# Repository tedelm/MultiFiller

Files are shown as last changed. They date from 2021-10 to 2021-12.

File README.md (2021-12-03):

# MultiFiller
Modular Beercan/Bottle filler </br></br>
MultiFiller is a OpenSource semi-auto beercan or bottle filler.</br></br>

!This is a "work in progress" project!

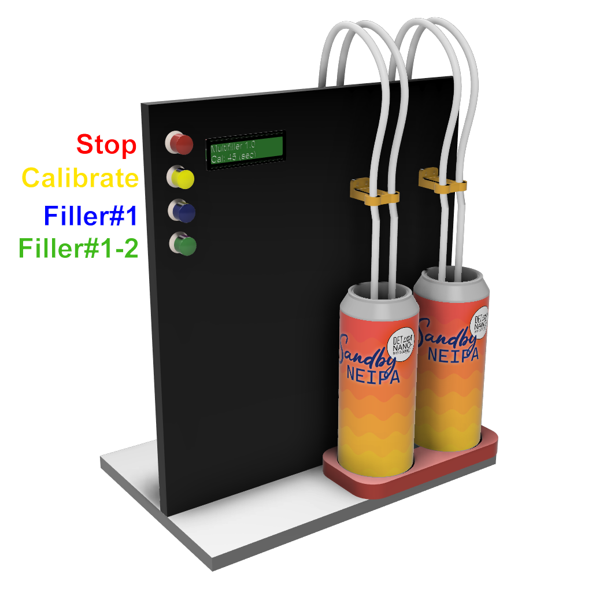
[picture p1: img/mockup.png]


## In action Youtube video
(https://youtu.be/LUoDoRMrJUI)

## Navigation 

* [Build](https://github.com/tedelm/MultiFiller/blob/main/Build/README.md)
* [Schematics](https://github.com/tedelm/MultiFiller/blob/main/Schematics/README.md)
* [Video(s)](https://youtu.be/LUoDoRMrJUI)
* [Parts](https://github.com/tedelm/MultiFiller/blob/main/Parts/readme.md)

## Todo/Checklist

Counter pressure filling

- [ ] Verify design
- [ ] Verify minimal foam build up when filling

## Counter Pressure filling

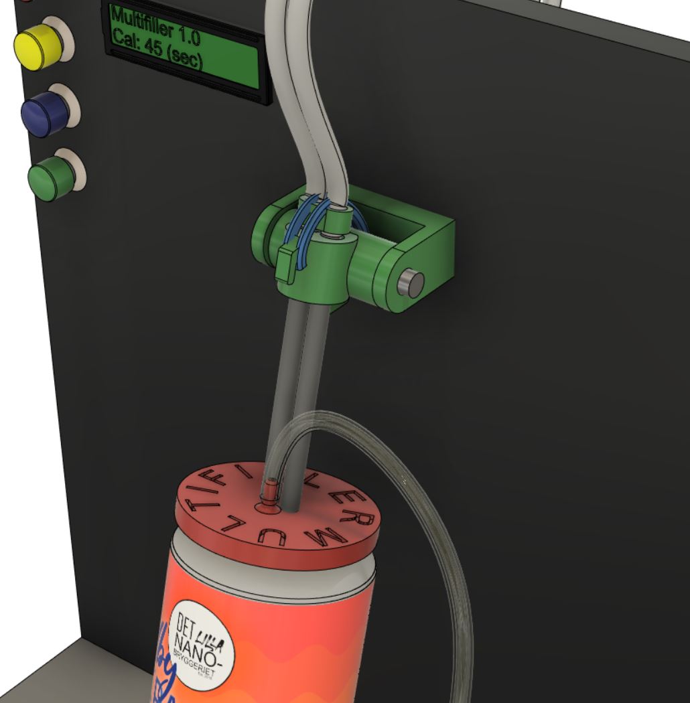
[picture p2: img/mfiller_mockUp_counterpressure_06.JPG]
</br>
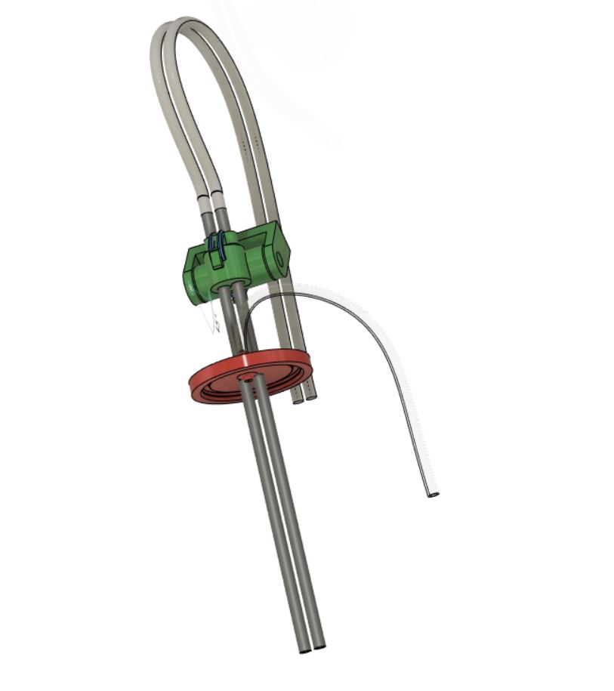
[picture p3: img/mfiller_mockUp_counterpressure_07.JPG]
</br>
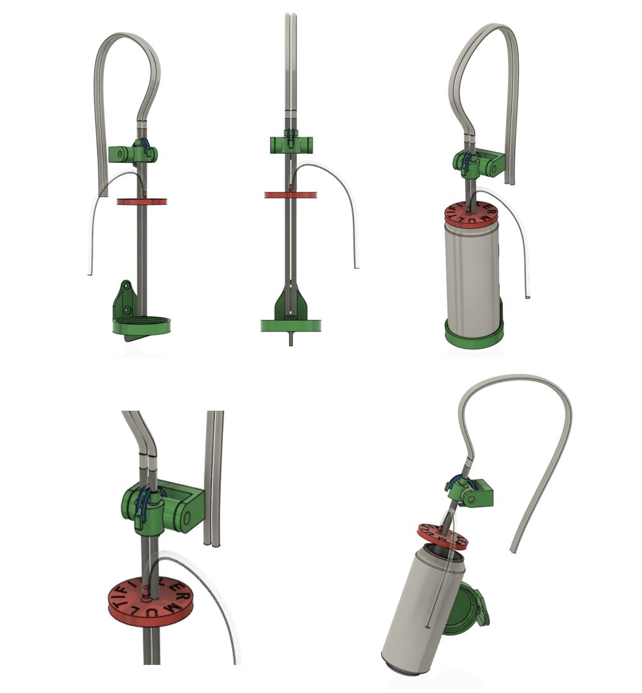
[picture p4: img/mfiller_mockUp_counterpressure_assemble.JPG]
</br>

Parts list:
- MFIller_CAN_CounterPressure_w_gasline_noVitamins-TPU.stl [STL List](https://github.com/tedelm/MultiFiller/tree/main/stl) or [Download - (RightClickSaveAs)](https://github.com/tedelm/MultiFiller/blob/main/stl/MFIller_CAN_CounterPressure_w_gasline_noVitamins-TPU.stl)
- MFiller_guide_cylinder_mount-PLA.stl  [STL List](https://github.com/tedelm/MultiFiller/tree/main/stl) or [Download - (RightClickSaveAs)](https://github.com/tedelm/MultiFiller/blob/main/stl/MFiller_guide_cylinder_mount-PLA.stl)
- MFiller_guide_cylinder-PLA_v1.1.stl  [STL List](https://github.com/tedelm/MultiFiller/tree/main/stl) or [Download - (RightClickSaveAs)](https://github.com/tedelm/MultiFiller/blob/main/stl/MFiller_guide_cylinder-PLA_v1.1.stl)
- MFiller_guide_cylinder-stopper-PLA_v1.1.stl   [STL List](https://github.com/tedelm/MultiFiller/tree/main/stl) or [Download - (RightClickSaveAs)](https://github.com/tedelm/MultiFiller/blob/main/stl/MFiller_guide_cylinder-stopper-PLA_v1.1.stl)
- MFiller_CAN_Shelf-PLA.stl    [STL List](https://github.com/tedelm/MultiFiller/tree/main/stl) or [Download - (RightClickSaveAs)](https://github.com/tedelm/MultiFiller/blob/main/stl/MFiller_CAN_Shelf-PLA.stl)
- 1/4" pipe/rod (stainless steel) [Link](https://www.maskindelen.se/product/rostfritt-ror-6x1)
- 1/4" tube (PVC/silicon) [Link](https://akvarieimporten.se/tillbehor/luftslang/pvc-luftslang-46-mm-transparent)
- 1/4" tube (PE) [Link](https://shop.humle.se/utrustning/slang/polyeten-pe/pe-slang-neutral-14-yd-per-meter)
- Rubberband (available at any random convenience store) [Link](https://www.clasohlson.com/se/Gummiband/p/Pr342290016)
- Optional:
    - Manual Air Valve 1/4" [Link](https://akvarieimporten.se/tillbehor/kopplingar-syresten/luftkran-i-plast-1-vags-for-luftslang-46-mm) (Could be used for Co2 inlet, Co2 Outlet, and beer lines)

</br>

# How to use
button#1 (Yellow) = Calibration (Press and hold)</br>
button#2 (Green)  = Filler #1 (Momentarily press)</br>
button#3 (Blue)   = Filler #1 and Filler #2 at same time (Momentarily press)</br>
button#4 (Red)    = Emergency shutdown (Press and hold)</br>

## Calibration
Button#1

    - Press and hold button#1 (it will start to pour beer from Filler #1)
    This is to calibrate how long it takes to fill your can or bottle
    When the can/bottle is filled to desired levels, release the button#1

</br>

## Test fill / Filler #1 
Button#2

    - Momentarily press button#2
       Filler#1: Co2 will purge for 4 seconds
       Filler#1: Beer flows for x (calibrated seconds)
       Filler#1: Co2 will purge on/off rapidly 8 times

## Filler #1 and #2
Button#3

    - Momentarily press button#3
       Filler#1 and #2: Co2 will purge for 4 seconds
       Filler#1 and #2: Beer flows for x (calibrated seconds)
       Filler#1 and #2: Co2 will purge on/off rapidly 8 times

</br>

## Emergency shutdown
button#4

    - Emergency shutdown (Press and hold)

</br>

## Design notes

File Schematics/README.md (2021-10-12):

# Schematics

</br>

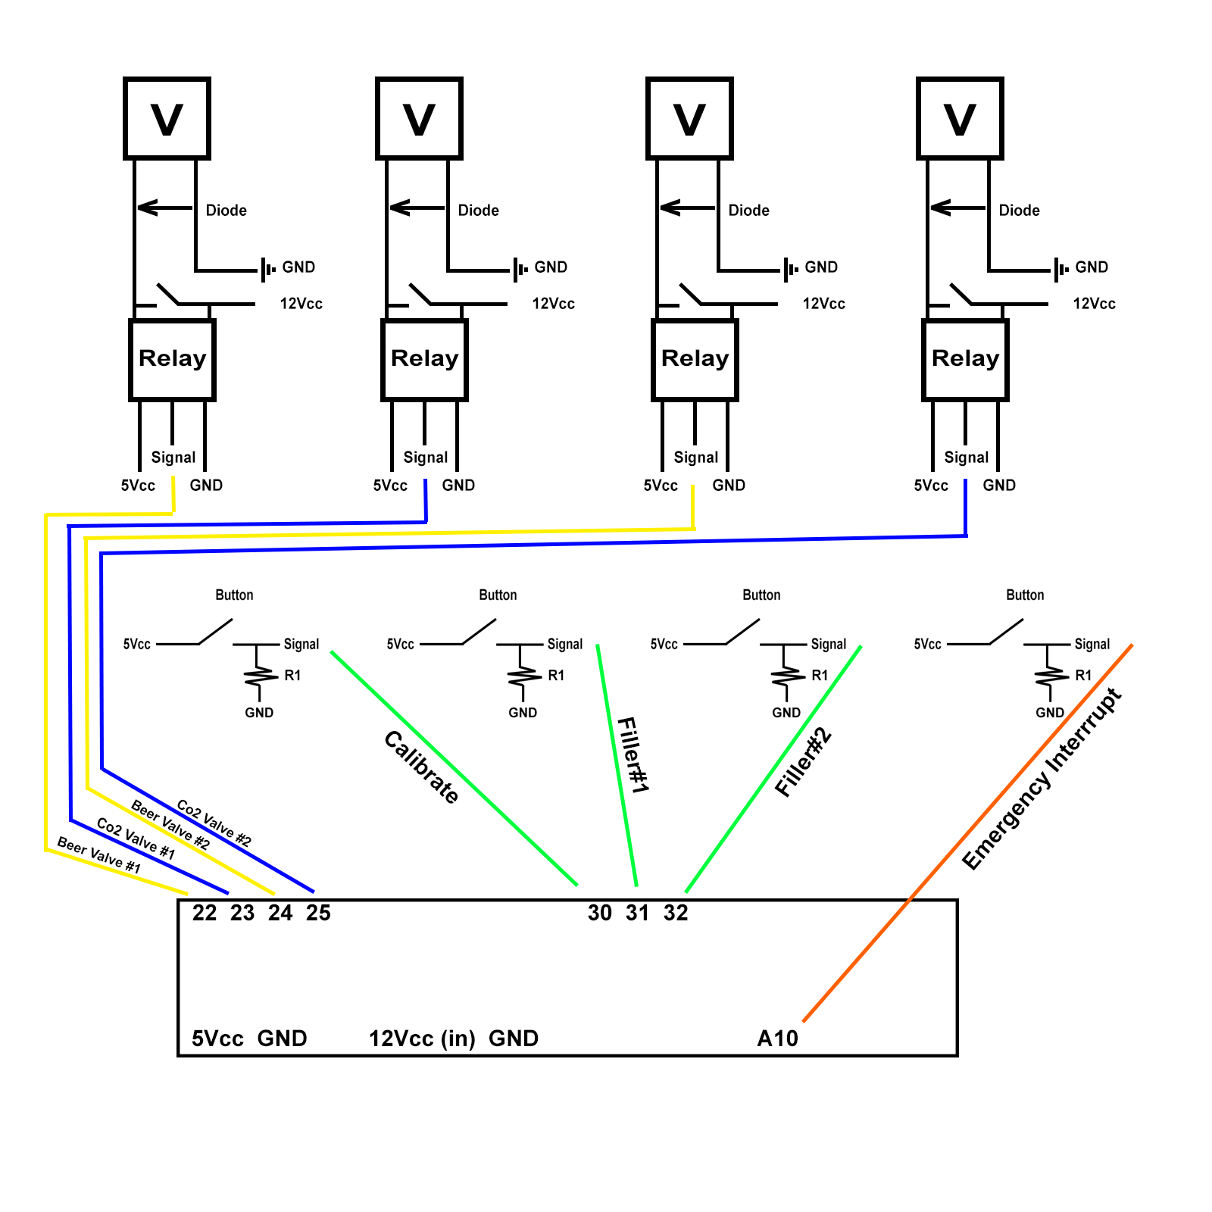
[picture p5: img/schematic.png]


</br>

## Buttons 
R1 = Resistor 10-50kOhm </br>
S = Signal, to arduino (eg. 30,31,32,A10)</br>

    //Calibrate - Time how long it takes to fill the can
    #define CalibrateButton 30 //Atmega328p-pu pin xx
    //Controller
    #define BeerFiller1Button 31 //Atmega328p-pu pin xx - Only Filler #1
    #define BeerFiller12Button 32 //Atmega328p-pu pin xx - Run both fillers
    #define EmergencyShutDownButton A10 //Atmega328p-pu interrupt pin xx - Stop everything
    //Arduino Uno/Nano/Mini: All pins are usable
    //Arduino Mega: 10, 11, 12, 13, 50, 51, 52, 53, A8 (62), A9 (63), A10 (64),A11 (65), A12 (66), A13 (67), A14 (68), A15 (69)

 </br>

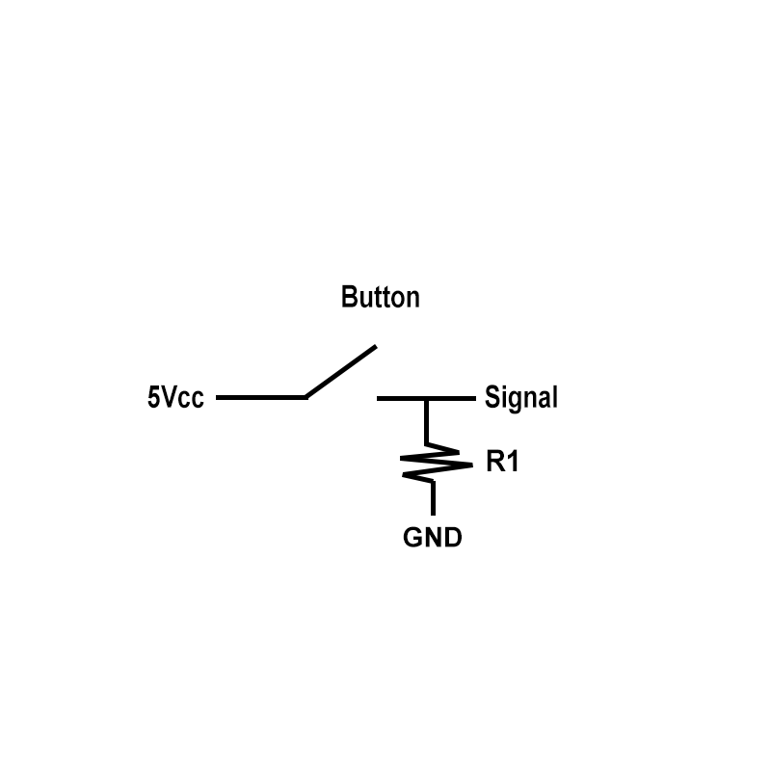
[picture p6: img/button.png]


## Relay and valves 
V = Solenoid valve</br>
<- = Diode </br>
S = Signal, to arduino (22,23,24,25)</br>

    //Filler 1
    #define BeerValve1 22 //Atmega328p-pu pin xx
    #define GasValve1 23 //Atmega328p-pu pin xx
    //Filler 2
    #define BeerValve2 24 //Atmega328p-pu pin xx
    #define GasValve2 25 //Atmega328p-pu pin xx

</br>

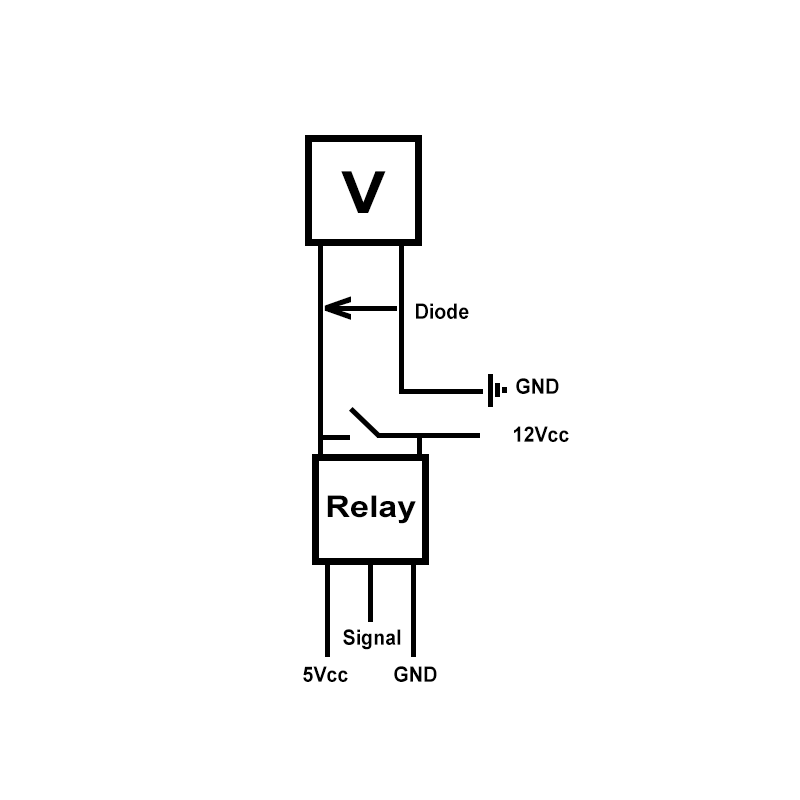
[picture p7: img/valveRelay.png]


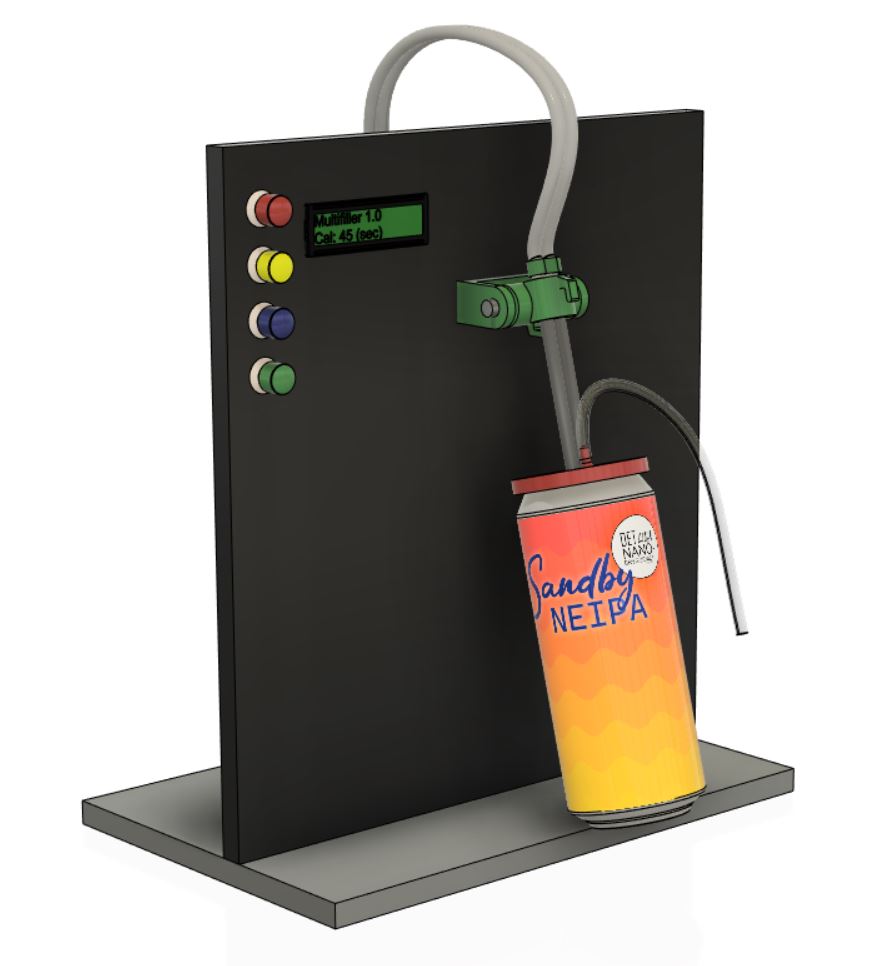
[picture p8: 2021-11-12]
img/mfiller_mockUp_counterpressure_04.JPG

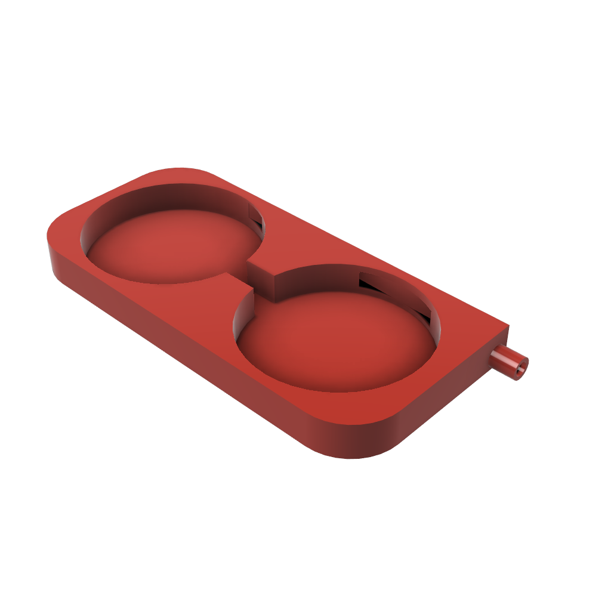
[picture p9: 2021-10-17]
img/can-tray.png

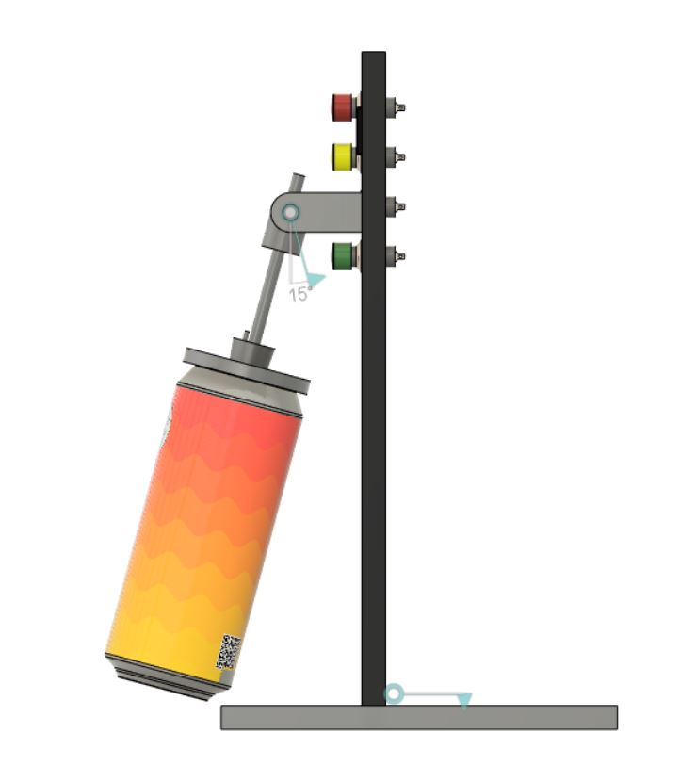
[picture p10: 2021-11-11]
img/mfiller_mockUp_counterpressure.JPG

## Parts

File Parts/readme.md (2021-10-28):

# Parts

## Single filler

|Pcs | Name | Price | Price subtotal (sek) | Description	| link |
| -- | --- | --- | --- | --- | ---- |
|2|12v solenoid valve - 1/4" (6,35mm) |	65  |130 |1 gas, 1 beer  |	https://www.wish.com/product/5de4e26dd52cb3c890403e0f|
|4|Diode (1N4001 DO-41 50V 1A) |	1.50  | 6 |Protect relay from solenoid kickback  |	https://www.electrokit.com/produkt/1n4001-do-41-50v-1a/|
|4|Resistor 0.25W 10-50kohm (10k) |	1  | 4 |Pulldown resistor  |	https://www.electrokit.com/produkt/motstand-kolfilm-0-25w-10kohm-10k/|
|2|PE-slang 1/4" (4,3 x 6,35 mm) neutral|	19	|38		|slang	 |https://shop.humle.se/utrustning/slang/polyeten-pe/pe-slang-neutral-14-yd-per-meter|
|2|PE-slang 3/8" (6,7 x 9,5 mm) neutral |	19  |38		|slang	 |https://shop.humle.se/utrustning/slang/polyeten-pe/pe-slang-neutral-38-yd-per-meter|
|0|John Guest 3/8", Y |	39	|0		|Y-koppling	 |https://shop.humle.se/utrustning/kopplingar/push-in-kopplingar-jg/jg-38/john-guest-38-y|
|2|John Guest 3/8" - 1/4" |	29	|58		|övergångs-koppling	|https://shop.humle.se/utrustning/kopplingar/push-in-kopplingar-jg/jg-38/john-guest-38-14-rak|
|2|silikonpropp 22/17 mm |	9	|18		|propp	 |https://shop.humle.se/utrustning/jasning/tillbehor/proppar/silikonpropp-2217-mm|
|1|John Guest 3/8" - 1/4" FFL |	39	|39	 |1 gas, 1 öl	öl/gas koppling	|https://shop.humle.se/utrustning/kopplingar/push-in-kopplingar-jg/jg-38/john-guest-38-14-ffl|
|1|PET-adapter (plast) |	69	|69		|gas-koppling	|https://shop.humle.se/utrustning/fattappning/servering/tillbehor-ovrigt/pet-adapter-plast|
|1|Gängad kulkoppling - 1/4" MFL - öl |	89	|89		|öl-koppling	|https://shop.humle.se/utrustning/kopplingar/fatkopplingar/kulkopplingar/ol/gangad-kulkoppling-14-mfl-ol|
|2|Arduino 5v relay |	39	|78		|relä	|https://cdon.se/bygg-verktyg/rela-5-volt-2-kanals-optikt-isolerad-passar-arduino-p49744000|
|1|Arduino nano |	40	|40		|micro controller	|https://www.banggood.com/Geekcreit-ATmega328P-Nano-V3-Controller-Board-Improved-Version-Module-Development-Board-p-940937.html?ID=6300464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|
|3|Momentary press button |	15	|45	|calibrate, filler1, filler 1 and 2	|https://www.electrokit.com/produkt/tryckknapp-1-pol-off-on-metall-bla-lodoron/|
|1| Patch cable ~5m |	99	|99	|Split and use as cabling	|https://www.electrokit.com/produkt/patchkabel-u-utp-cat6a-5m-gra/|

## Dual filler
Just add some more solenoid valves, relays and tubing

|Pcs | Name | Price | Price subtotal (sek) | Description	| link |
| -- | --- | --- | --- | --- | ---- |
|4|12v solenoid valve - 1/4" (6,35mm) |	65  |130 |2 gas, 2 beer  |	https://www.wish.com/product/5de4e26dd52cb3c890403e0f|
|4|Diode (1N4001 DO-41 50V 1A) |	1.50  | 6 |Protect relay from solenoid kickback  |	https://www.electrokit.com/produkt/1n4001-do-41-50v-1a/|
|4|Resistor 0.25W 10-50kohm (10k) |	1  | 4 |Pulldown resistor  |	https://www.electrokit.com/produkt/motstand-kolfilm-0-25w-10kohm-10k/|
|4|PE-slang 1/4" (4,3 x 6,35 mm) neutral|	19	|38		|slang	 |https://shop.humle.se/utrustning/slang/polyeten-pe/pe-slang-neutral-14-yd-per-meter|
|4|PE-slang 3/8" (6,7 x 9,5 mm) neutral |	19  |38		|slang	 |https://shop.humle.se/utrustning/slang/polyeten-pe/pe-slang-neutral-38-yd-per-meter|
|2|John Guest 3/8", Y |	39	|0		|Y-koppling	 |https://shop.humle.se/utrustning/kopplingar/push-in-kopplingar-jg/jg-38/john-guest-38-y|
|4|John Guest 3/8" - 1/4" |	29	|58		|övergångs-koppling	|https://shop.humle.se/utrustning/kopplingar/push-in-kopplingar-jg/jg-38/john-guest-38-14-rak|
|4|silikonpropp 22/17 mm |	9	|18		|propp	 |https://shop.humle.se/utrustning/jasning/tillbehor/proppar/silikonpropp-2217-mm|
|2|John Guest 3/8" - 1/4" FFL |	39	|39	 |1 gas, 1 öl	öl/gas koppling	|https://shop.humle.se/utrustning/kopplingar/push-in-kopplingar-jg/jg-38/john-guest-38-14-ffl|
|2|PET-adapter (plast) |	69	|69		|gas-koppling	|https://shop.humle.se/utrustning/fattappning/servering/tillbehor-ovrigt/pet-adapter-plast|
|2|Gängad kulkoppling - 1/4" MFL - öl |	89	|89		|öl-koppling	|https://shop.humle.se/utrustning/kopplingar/fatkopplingar/kulkopplingar/ol/gangad-kulkoppling-14-mfl-ol|
|1| 4in1 Arduino 5v relay |	50	|50		|relay	|https://www.banggood.com/Geekcreit-5V-4-Channel-Relay-Module-For-PIC-ARM-DSP-AVR-MSP430-Geekcreit-for-Arduino-products-that-work-with-official-Arduino-boards-p-87987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|
|1|Arduino nano |	40	|40		|micro controller	|https://www.banggood.com/Geekcreit-ATmega328P-Nano-V3-Controller-Board-Improved-Version-Module-Development-Board-p-940937.html?ID=6300464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|
|4|Momentary press button |	15	|60	|calibrate, filler1, filler 1 and 2	|https://www.electrokit.com/produkt/tryckknapp-1-pol-off-on-metall-bla-lodoron/|
|1| Patch cable ~5m |	99	|99	|Split and use as cabling	|https://www.electrokit.com/produkt/patchkabel-u-utp-cat6a-5m-gra/|

## Solenoid valve specs

Power: Solenoid
Port Size: 1/4" (6,35mm) or 3/8" (9.52mm)
Model Number: 1/4" OR 3/8" OD
Standard or Nonstandard: Standard
Temperature of Media: Normal Temperature
Material: Plastic
Structure: Diaphragm
Pressure: 0-0.8Mpa
Media: Water, air, oil. etc.
Voltage:: DC 12V
Port:: 1/4", 3/8" OD Hose
Power: Solenoid
Material: Plastic

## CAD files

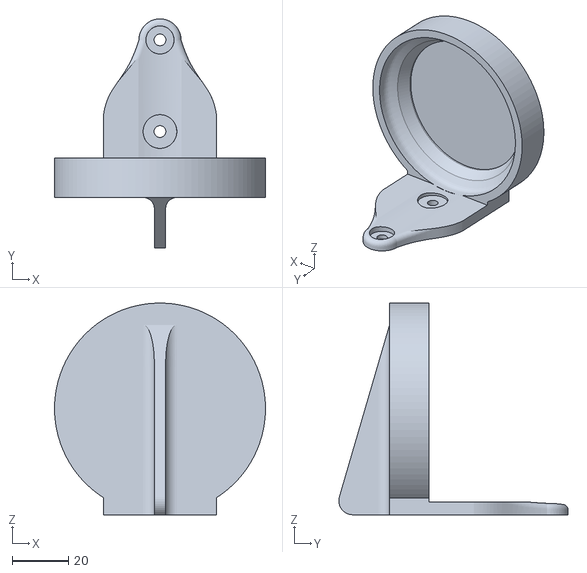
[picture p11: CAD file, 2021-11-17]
stl/MFiller_CAN_Shelf-PLA.stl
75.0 x 81.5 x 75.3

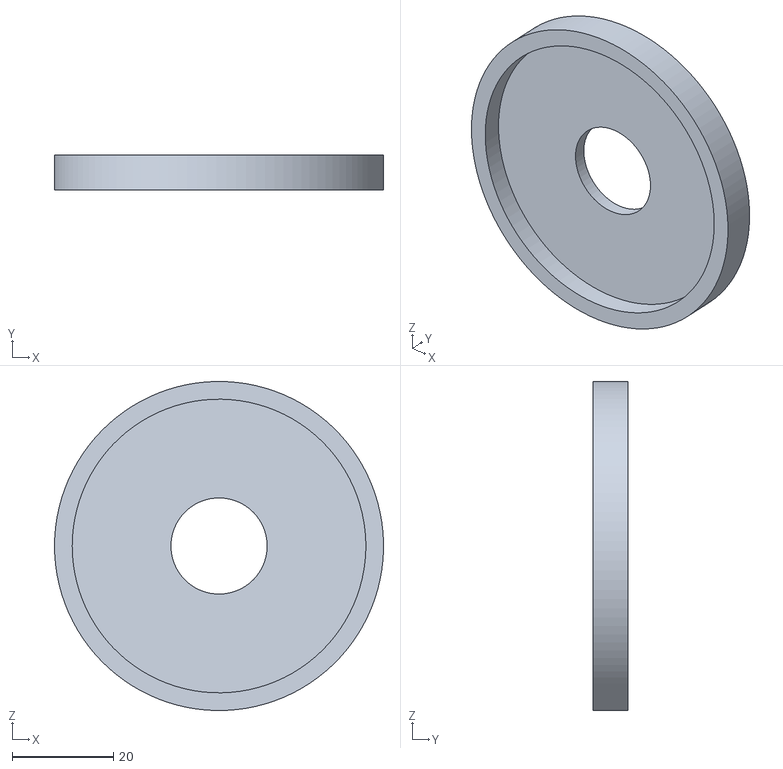
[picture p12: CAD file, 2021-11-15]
stl/MFIller_CAN_CounterPressure-TPU.stl
65.0 x 7.00 x 65.0

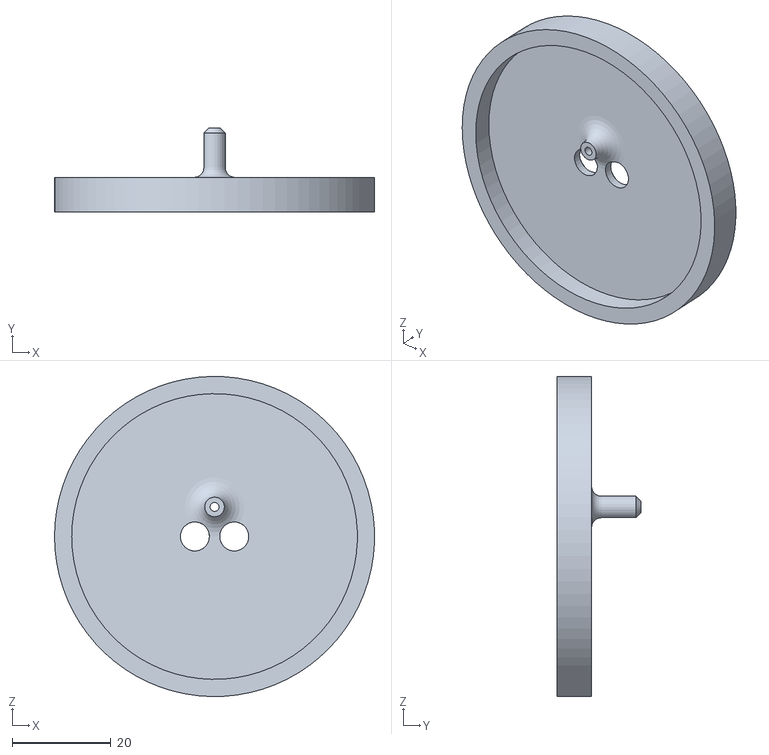
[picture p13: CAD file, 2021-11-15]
stl/MFIller_CAN_CounterPressure_w_gasline_noVitamins-TPU.stl
65.0 x 17.0 x 65.0

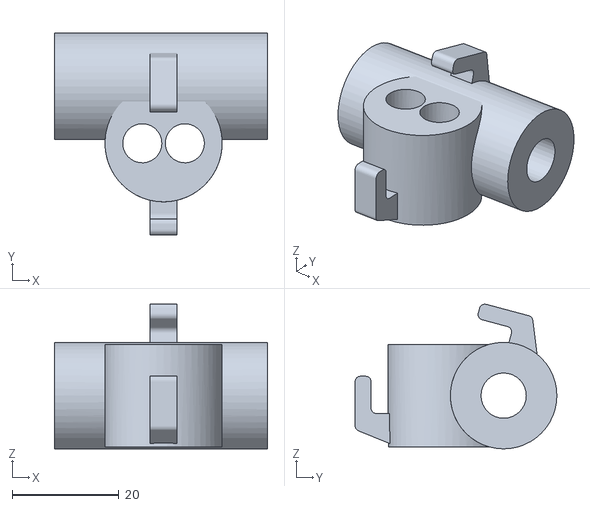
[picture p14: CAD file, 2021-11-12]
stl/MFiller_guide_cylinder-PLA_v1.1.stl
40.0 x 37.9 x 27.2

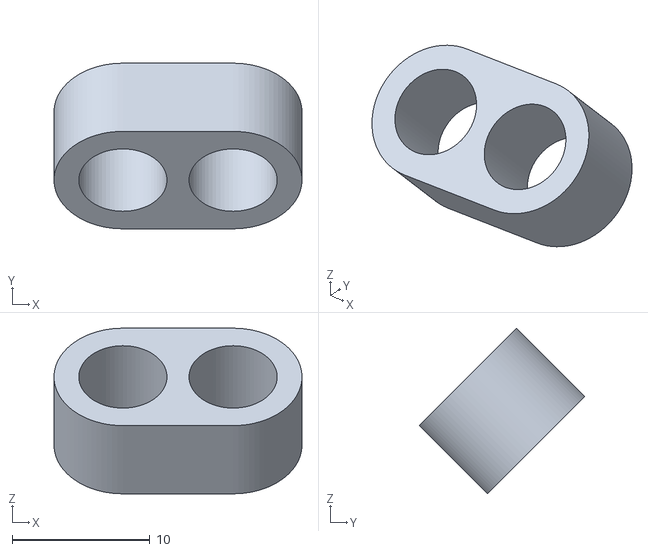
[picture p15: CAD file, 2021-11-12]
stl/MFiller_guide_cylinder-stopper-PLA_v1.1.stl
18.0 x 12.0 x 12.0

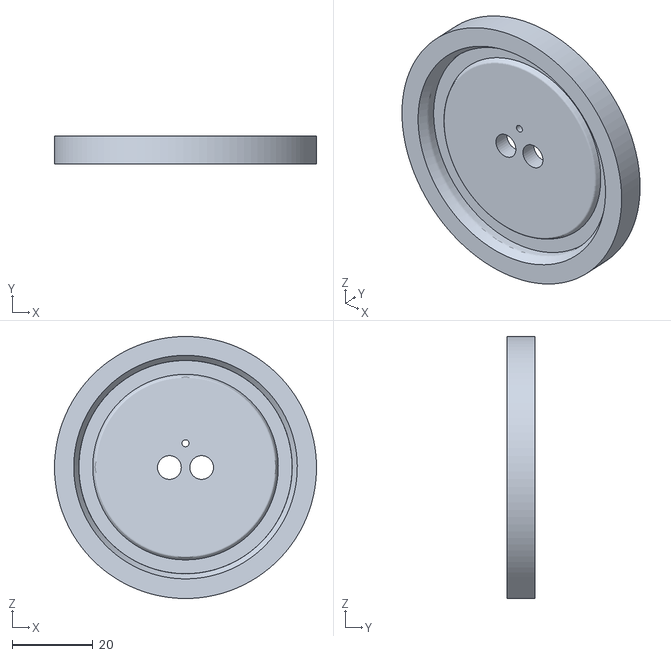
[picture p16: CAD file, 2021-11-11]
stl/MFIller_CAN_CounterPressure_noVitamins-TPU.stl
65.0 x 7.00 x 65.0

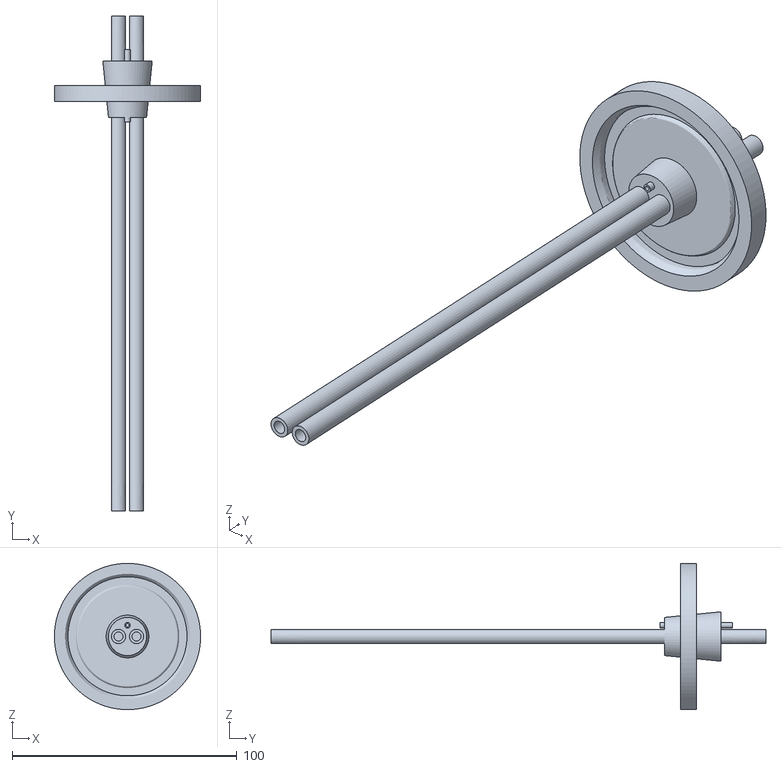
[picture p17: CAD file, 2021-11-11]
stl/Mockup_CounterPressure.stl
65.0 x 220.0 x 65.0

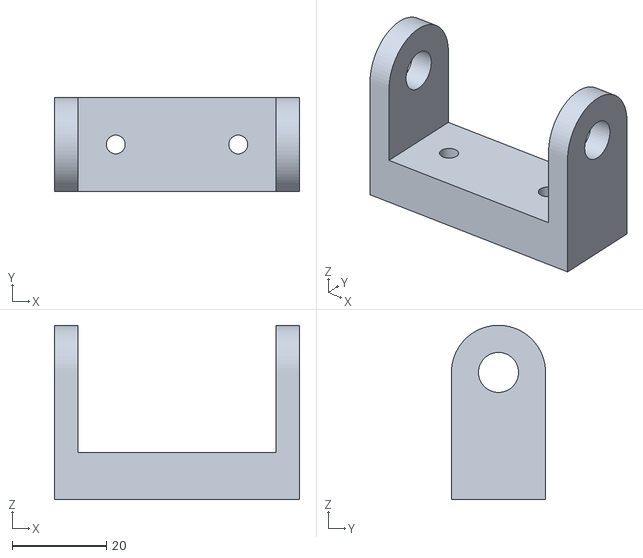
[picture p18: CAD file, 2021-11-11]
stl/MFiller_guide_cylinder_mount-PLA.stl
52.0 x 20.0 x 37.0

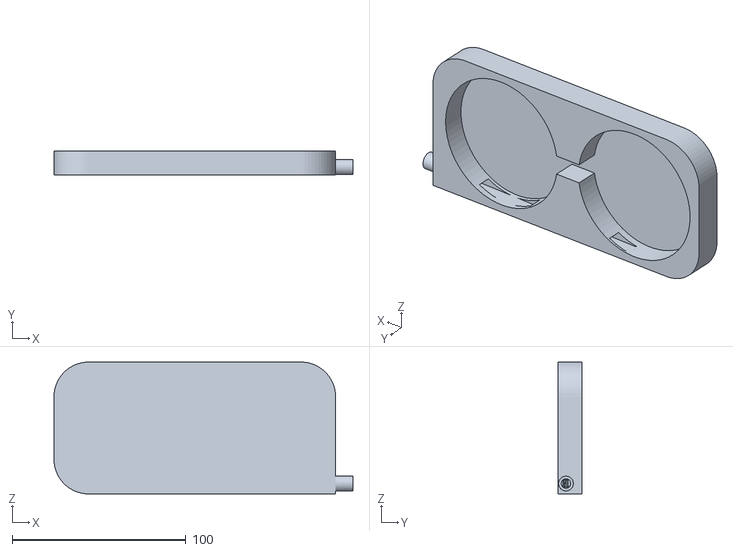
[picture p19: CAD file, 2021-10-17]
stl/can-tray.stl
172.3 x 14.0 x 76.0

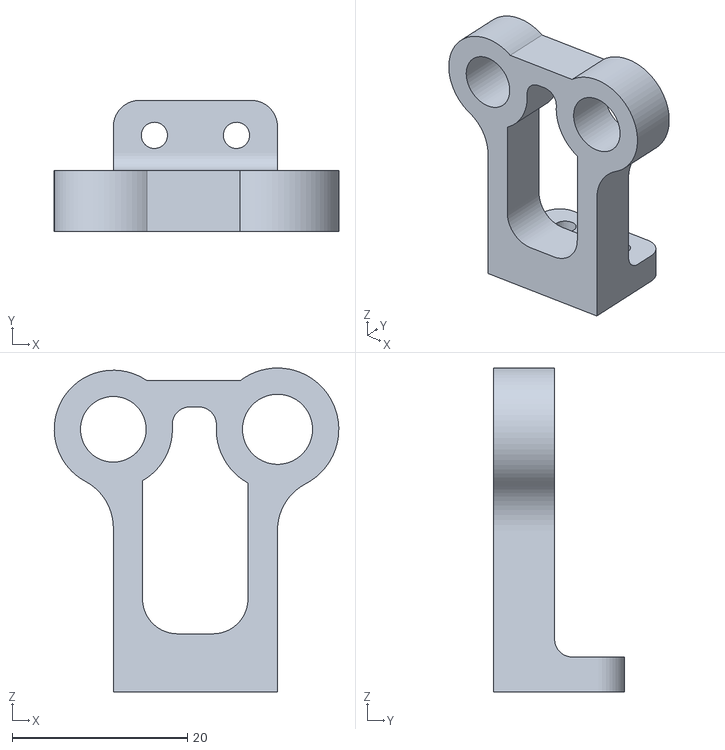
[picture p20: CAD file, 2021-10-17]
stl/line-guide_v2.stl
32.5 x 15.0 x 37.0

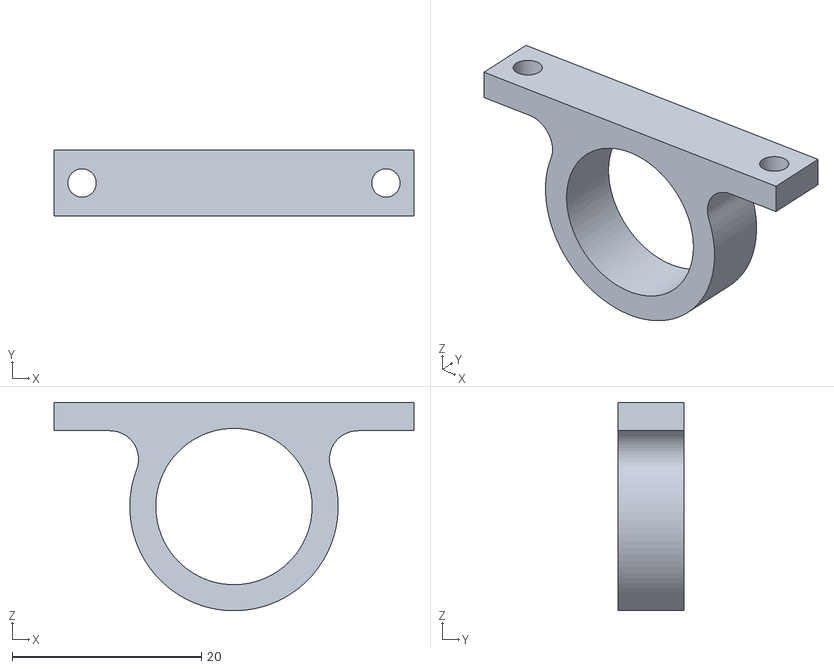
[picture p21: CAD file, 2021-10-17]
stl/Valve-clamp.stl
38.0 x 7.00 x 22.0

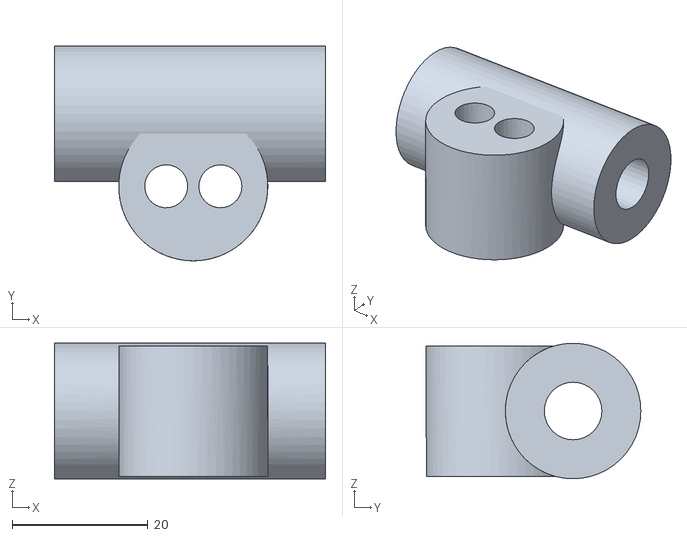
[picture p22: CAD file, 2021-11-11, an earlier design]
stl/MFiller_guide_cylinder-PLA.stl
40.0 x 31.7 x 20.0

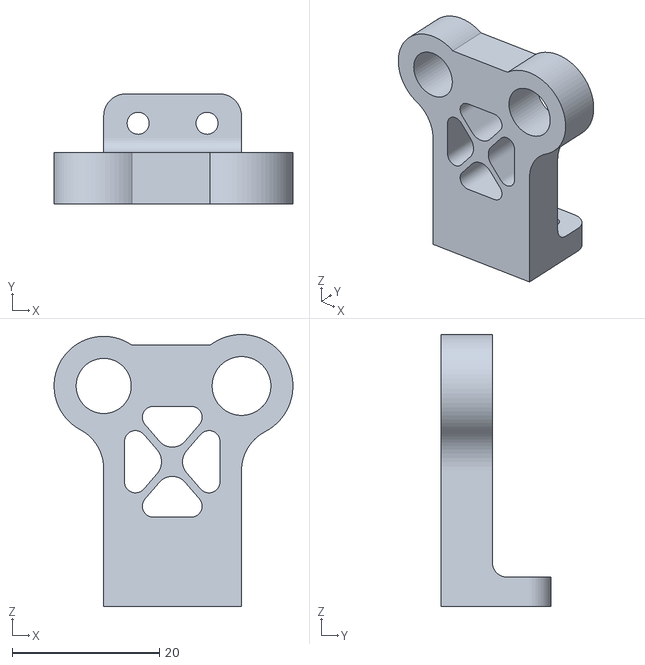
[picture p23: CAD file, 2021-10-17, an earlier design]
stl/line-guide.stl
32.5 x 15.0 x 37.0

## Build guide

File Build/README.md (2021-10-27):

# Build

    Specs:
    Front  W: 300 H: 300
    Bottom W: 300 D: 200

</br>

Found some 12mm plywood laying around :)</br>

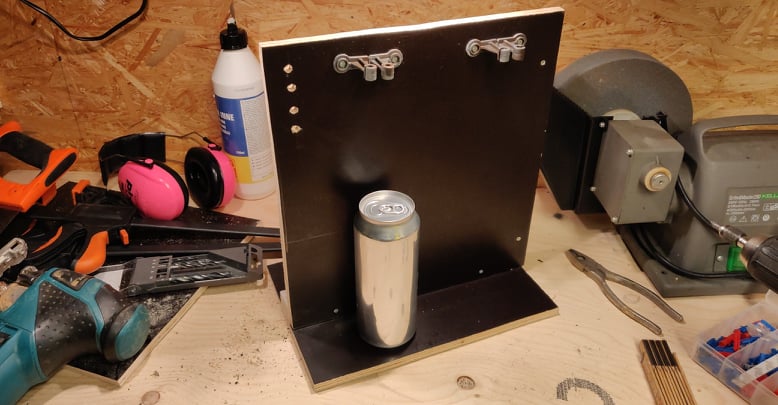
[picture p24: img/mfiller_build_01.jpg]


</br>

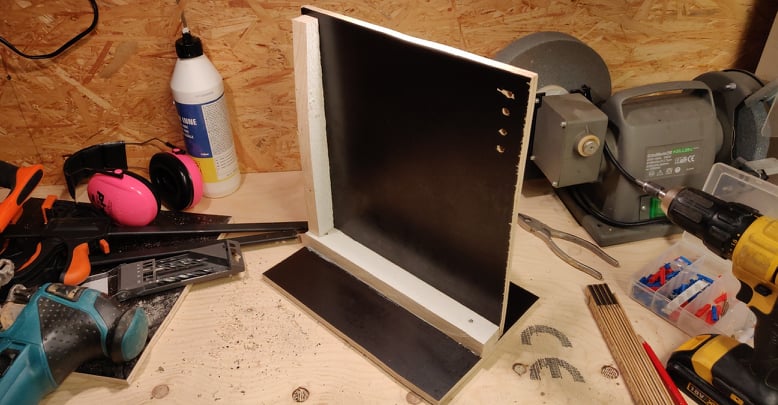
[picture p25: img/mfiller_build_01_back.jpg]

</br>

The holes did not work out... so cut some more out to fit the buttons and screen. Then added clear plexy </br>
3d printed some mounts/guides for the tubing and going to add a screen protector (Its not fitted that good :D )</br>

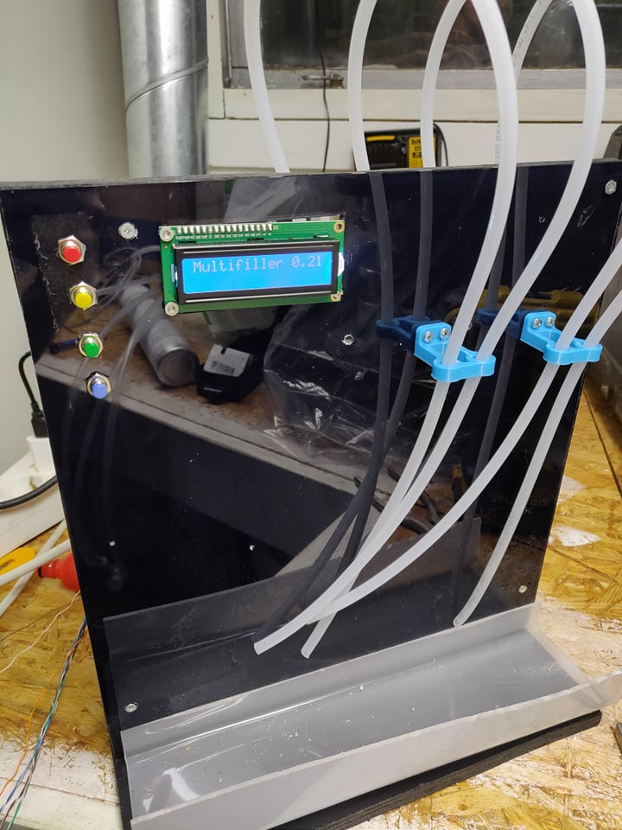
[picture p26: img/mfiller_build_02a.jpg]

</br>

3D Printed fittings to hold the valves</br>

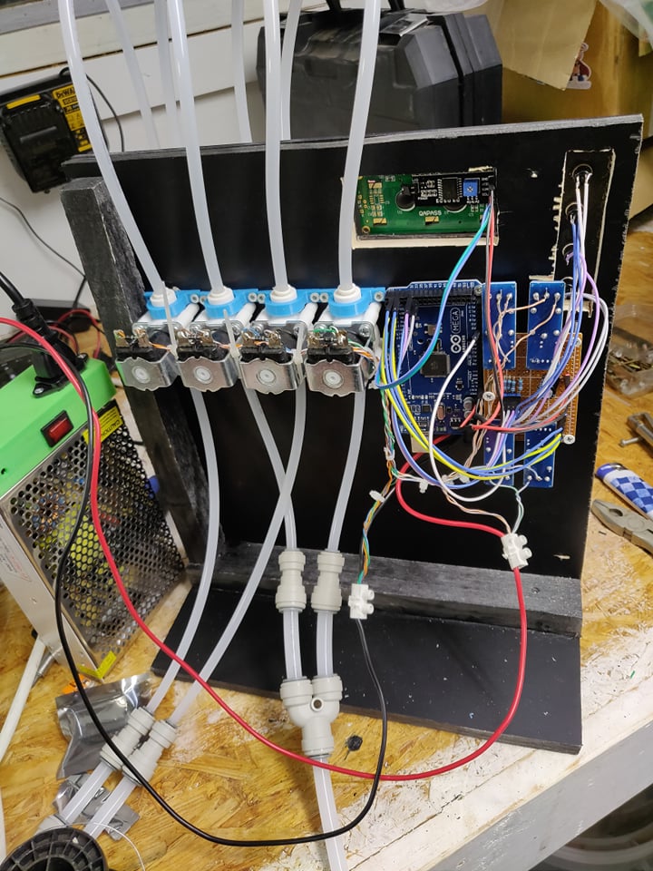
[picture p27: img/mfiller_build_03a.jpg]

</br>

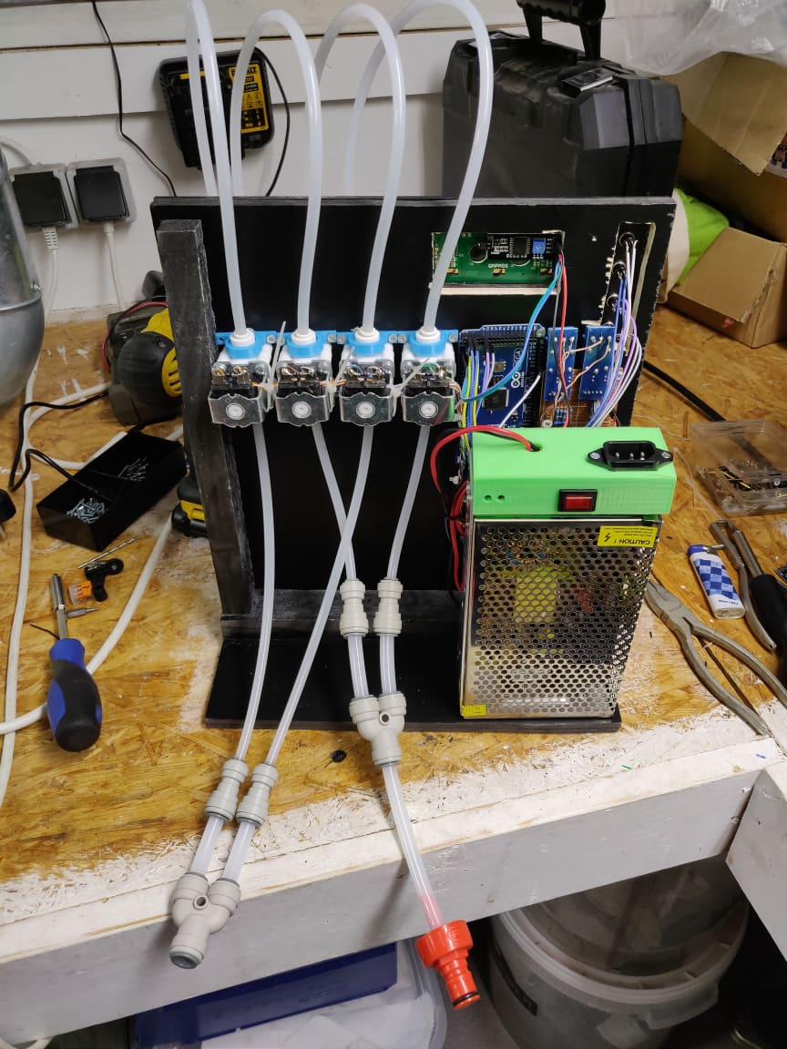
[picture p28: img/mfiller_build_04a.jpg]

</br>



</br>
I really need to make this into a box...</br>

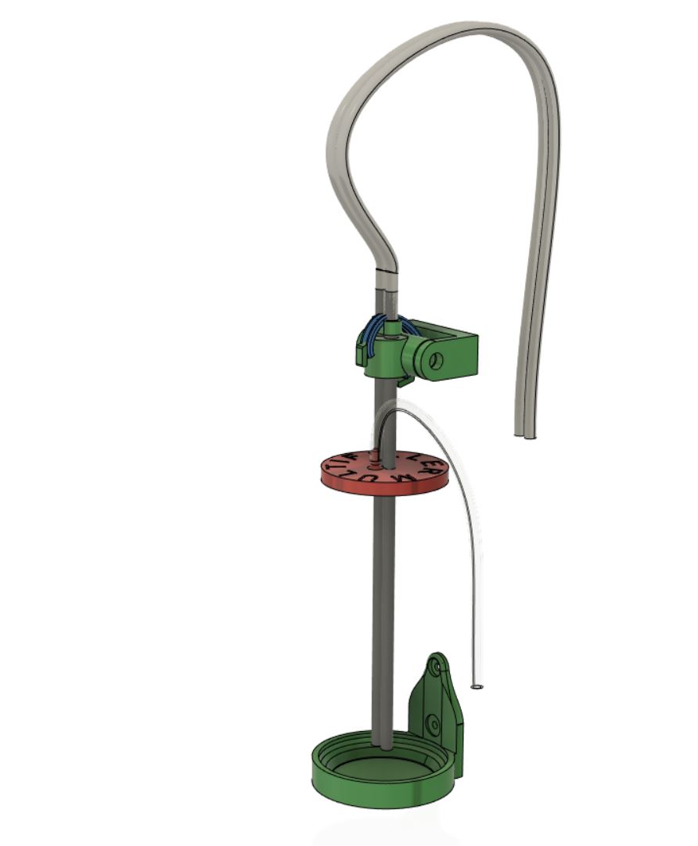
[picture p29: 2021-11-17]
img/mfiller_mockUp_counterpressure_assemble_02.JPG

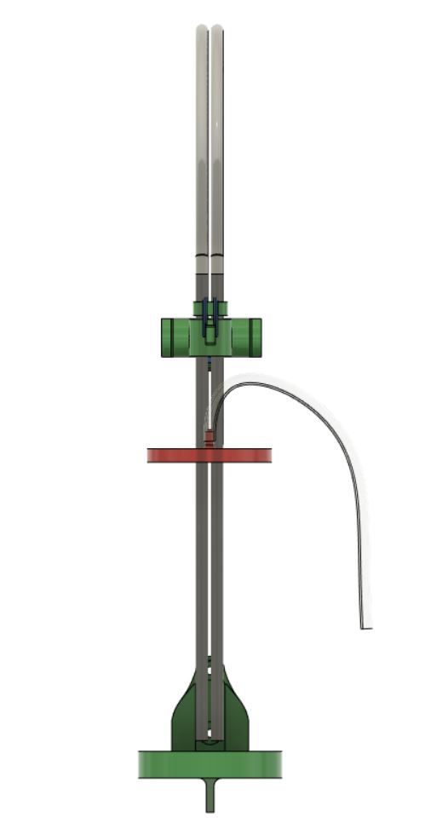
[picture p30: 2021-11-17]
img/mfiller_mockUp_counterpressure_assemble_03.JPG

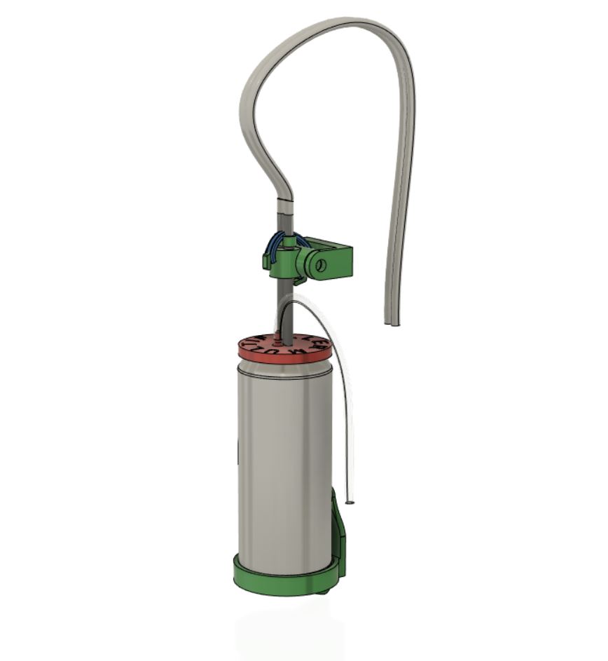
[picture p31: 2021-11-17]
img/mfiller_mockUp_counterpressure_assemble_01.JPG

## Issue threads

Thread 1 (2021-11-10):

Mottrycksfyllning

NoNameWhatever, 2021-11-10:
Har kollat på detta ett tag nu.

Nuläge:
Denna metod fungerar bra för öl som ska kolsyras i flaska med hjälp av socker.

Förslag på utveckling till att mottrycksfylla.

Varför?
Kolsyrad öl måste fyllas i flaska/burk via mottrycksfyllning.
Det är för att ölen ska hålla sig utan att oxidera.

Hur?
Öppningen måste vara tät och hålla tätt trots ökat tryck i flaska/burk.
Tre ledningar måste genomföras genom tätningen för att kunna mottrycksfylla.
1. Ledning för ölen
2. Ledning för gasen för att dels tömma flaskan på syre och öka trycket.
3. Ledning för att dumpa tryck/syre/skum

Problem/Utmaning:
1. Styra gasventil för rätt tryck. Behöver kunna reglera flödet. Inte bara öppet/stäng.
2. Mäta hur mycket som fylls. Flödesmätare?
3. Reglera dumpningen då denna styr flödet in i flaskan/burken genom att minska trycket i förhållande till ölen. Måste vara reglerbar. Är det möjligt att kunna ställa in vilken tryckskillnad det ska vara?

Callwater, 2021-11-10:
Jag fyller flaskor med en mottrycksfyllare nu och förstår vad du menar.

Men det finns ju en kommersiell produkt,                ”Duofiller” som den här är baserad på, och vad jag förstår funkar den utan bekymmer, man ser den lite överallt.

https://www.instagram.com/p/CKw1E4QKzEW/?utm_medium=copy_link

Så jag undrar hur mycket man ska lägga ned på mottryck

tedelm, 2021-11-11:
Härligt att ni engagera er i projektet!
Jag har äntligen fått rätt på Fusion360 igen och börjat klura på en mottrycksfyllare (Har en som passar ghettofiller).
Ventiler för att ställa co2 trycket/flödet testar jag nu akvarie-pumps-ventiler, små och billiga, passar 1/4" slang.
Sedan har jag hittat 1/4" rostfria rör som kommer användas. uppdaterar inköpslistan när jag testat.

https://github.com/tedelm/MultiFiller/blob/main/img/mfiller_mockUp_counterpressure.JPG
https://github.com/tedelm/MultiFiller/blob/main/img/mfiller_mockUp_counterpressure_01.JPG
https://github.com/tedelm/MultiFiller/blob/main/img/mfiller_mockUp_counterpressure_02.JPG
https://github.com/tedelm/MultiFiller/blob/main/img/mfiller_mockUp_counterpressure_03.JPG

tedelm, 2021-11-11:
Väntar just nu på att få lite delar utskrivna för att testa ...

https://github.com/tedelm/MultiFiller/blob/main/stl/MFIller_CAN_CounterPressure_w_gasline_noVitamins-TPU.stl
https://github.com/tedelm/MultiFiller/blob/main/stl/Mockup_CounterPressure.stl

Callwater, 2021-11-17:
Fortsätter den här tråden med en mottrycks lösning för flaskor som jag håller på med, väntar på att få magnetventilen bara innan jag kan börja pröva skarpt.

Men tanken är att den ska vara fullt utbytbar mot @tedelm delar för burkfyllning

https://github.com/Callwater/MultiFiller/blob/main/img/Bottle%20Counter%20pressure%20mockup%201.JPG
https://github.com/Callwater/MultiFiller/blob/main/img/Bottle%20Counter%20pressure%20mockup%202.JPG
https://github.com/Callwater/MultiFiller/blob/main/img/Bottle%20Counter%20pressure%20testfit.mp4

tedelm, 2021-11-17:
Aah, snyggt! Kul det händer grejer!
Det finns även möjlighet att använda en silikon propp och borra tre hål i den. Likt ghetto filler.

Jag har uppdaterat med en hylla för att ställa burken på. En hylla som går att rotera för att lättare lossa burken efter fyllning.

https://github.com/tedelm/MultiFiller#counter-pressure-filling

NoNameWhatever, 2021-11-17:
Vad sägs om en discord för lite snabbare kommunikation samt stöta och blöta lösningar?

Callwater, 2021-11-17:
En discord tycker jag låter som ett bra forum för att dela idéer 👌

Callwater, 2021-11-17:
https://discord.gg/Vy2TcuyW

Har skapat kanalen nu, välkomna in @NoNameWhatever @tedelm

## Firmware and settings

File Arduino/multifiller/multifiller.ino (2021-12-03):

#include "EEPROM.h"
#include "PinChangeInt.h"
#include <Wire.h>
#include "LiquidCrystal_I2C.h" //https://github.com/fdebrabander/Arduino-LiquidCrystal-I2C-library

//LCD Screen 1602 I2C
#define LcdSDApin 20 //Communication I2C Pin (SDA) - Nano A4 / Mega 20 
#define LcdSCLpin 21 //Communication I2C Pin (SCL) - Nano A5 / Mega 21
LiquidCrystal_I2C lcd(0x27, 16, 2); // I2C address 0x27, 16 column and 2 rows

//Calibrate - Time how long it takes to fill the can
#define CalibrateButton 30 //Atmega328p-pu pin xx

//Controller
#define BeerFiller1Button 31 //Atmega328p-pu pin xx - Only Filler #1 
#define BeerFiller12Button 32 //Atmega328p-pu pin xx - Run both fillers
#define EmergencyShutDownButton A10 //Atmega328p-pu interrupt pin xx - Stop everything
//Arduino Uno/Nano/Mini: All pins are usable
//Arduino Mega: 10, 11, 12, 13, 50, 51, 52, 53, A8 (62), A9 (63), A10 (64),A11 (65), A12 (66), A13 (67), A14 (68), A15 (69)

//Filler 1
#define BeerValve1 22 //Atmega328p-pu pin xx
#define GasValve1 23 //Atmega328p-pu pin xx
//Filler 2
#define BeerValve2 24 //Atmega328p-pu pin xx
#define GasValve2 25 //Atmega328p-pu pin xx

//Define values
float mfVersion = 0.25; // Firmware Version
int BothCanFillupComp = 1.20; // Fillup compensation for pressure loss 1.20 = 20% extra
int CanFillUpTimeCalibrated = 0;
int CanFillUpTime = 0; // Count loops (to be able to store 255 max loops), multiply with CountDelayValueMs
int Calibratedms = 0;
int CountDelayValueMs = 500; //should not be lower than 250
float pressedSeconds = millis();
int countButtonPress = 0;
int Co2PurgeBeforeDelay = 2500; //2,5 seconds
int Co2PurgeAfterCountLimit = 1; // on/off 1 times
int Co2PurgeAfterCount = 0; // Count
long buttonTimer = 0;
long longPressTime = 1000;
boolean buttonActive = false;
boolean longPressActive = false;


void setup() {
  // put your setup code here, to run once:
  Serial.begin(9600);
  Serial.println("Startup...");

  //LCD
  write2LCD(0,0,"Multifiller " + String(mfVersion),0,1," ");

  //CalibrateButton
  pinMode(CalibrateButton,INPUT);
  //Controller
  pinMode(BeerFiller1Button,INPUT);
  pinMode(BeerFiller12Button,INPUT);
  pinMode(EmergencyShutDownButton,INPUT);
  
  //Filler 1
  pinMode(BeerValve1,OUTPUT);
  pinMode(GasValve1,OUTPUT);
  //Filler 2
  pinMode(BeerValve2,OUTPUT);
  pinMode(GasValve2,OUTPUT);

  Serial.println("Startup complete!");
  Serial.println("Waiting for input!");
  Serial.println("..."); 

  attachPinChangeInterrupt(EmergencyShutDownButton, EmergencyShutDownButtonFunction, CHANGE);
}

//LCD write2LCD(0,0,"Multifiller",0,1,"Values")
void write2LCD(int OffsetColumn, int OffsetRow, const String &strToWrite, int OffsetColumn2, int OffsetRow2, const String &strToWrite2){
  lcd.begin();
  lcd.backlight();
  lcd.clear();
  lcd.setCursor(OffsetColumn,OffsetRow); //The cursor is at 4th column(count from 0), and 0th row(count from 0)
  lcd.print(strToWrite);
  lcd.setCursor(OffsetColumn2,OffsetRow2); //The cursor is at 4th column(count from 0), and 0th row(count from 0)
  lcd.print(strToWrite2);  
}


//EEPROM Write, writeEEPROM(0, "Hello Arduino");
void writeEEPROM(int addrOffset, const String &strToWrite){
  byte len = strToWrite.length();
  EEPROM.update(addrOffset, len);
  for (int i = 0; i < len; i++){
    EEPROM.update(addrOffset + 1 + i, strToWrite[i]);
  }
}

//EEPROM Read, readEEPROM(0);
String readEEPROM(int addrOffset){
  int newStrLen = EEPROM.read(addrOffset);
  char data[newStrLen + 1];

  for (int i = 0; i < newStrLen; i++){
    data[i] = EEPROM.read(addrOffset + 1 + i);
  }
  data[newStrLen] = '\ 0'; // !!! NOTE !!! Remove the space between the slash "/" and "0" (I've added a space because otherwise there is a display bug)

  //Fix trailing scrap data
  String EEPROMData = String(data);
  int StringIndex = EEPROMData.length() - 1;
  EEPROMData.remove(StringIndex, 1); 
  return String(EEPROMData);
}

void loop() {
  // put your main code here, to run repeatedly:

    //Check if calibration button is pressed short or long
    if (digitalRead(CalibrateButton) == HIGH) {
      if (buttonActive == false) {
        buttonActive = true;
        buttonTimer = millis();
      }
      if ((millis() - buttonTimer > longPressTime) && (longPressActive == false)) {
        longPressActive = true;
        Serial.println("CalibrateButton pressed - Long");
        CalibrateButtonFunction();
        delay(250);        
      }else{
          Serial.println("CalibrateButton pressed - Short");
          CalibrateButtonPressFunction();
          delay(250);
      }
    } else {
      if (buttonActive == true) {
        if (longPressActive == true) {
          longPressActive = false;
        }
        buttonActive = false;
      }
    }  

  // BeerFiller1Button
  if (digitalRead(BeerFiller1Button) == HIGH) {
    Serial.println("BeerFiller1Button pressed");
    BeerFiller1ButtonFunction();
    delay(250);
  }

  // BeerFiller12Button
  if (digitalRead(BeerFiller12Button) == HIGH) {
    Serial.println("BeerFiller12Button pressed");
    BeerFiller12ButtonFunction();
    delay(25);
  }

  delay(100);
}

//Calibrate the time it takes to fill a can
void CalibrateButtonFunction(){
    int CanFillUpTimeCalibrated = 0;

    Serial.println("Calibrating");
    write2LCD(0,0,"Multifiller " + String(mfVersion),0,1,"Calibrating...");

    unsigned long TimeRightNow = millis();
    
    while(digitalRead(CalibrateButton) == HIGH){
      Serial.print(".");
      //Start filling beer
      digitalWrite(BeerValve1,HIGH);
      pressedSeconds = (millis() - TimeRightNow) / 1000;
      Serial.print(String(pressedSeconds));

      write2LCD(0,0,"Multifiller " + String(mfVersion),0,1,"Cal (s):" + String(pressedSeconds));
      delay(25);

    }
    //Stop filling beer
    digitalWrite(BeerValve1,LOW);
    
    Serial.println(" ");
    Serial.println("Saving to EEPROM... (Value in s):" + String(pressedSeconds));

    //Write to EEPROM
    writeEEPROM(0, String(pressedSeconds));
    //EEPROM.update(0, CanFillUpTime);
    Serial.println("Saved");

    String FetchedStrCanFillUpTimeMS = readEEPROM(0);
    Serial.println("Read from EEPROM: " + String(FetchedStrCanFillUpTimeMS));

    write2LCD(0,0,"Multifiller " + String(mfVersion),0,1,"Cal (s):" + String(FetchedStrCanFillUpTimeMS));
}

//Calibrate the time it takes to fill a can
void CalibrateButtonPressFunction(){
    String FetchedStrCanFillUpTimeMS = readEEPROM(0);
    int CanFillUpTime = FetchedStrCanFillUpTimeMS.toInt() + 1; //Add 1 seconds per press
    //Write to EEPROM
    writeEEPROM(0, String(CanFillUpTime));
    Serial.println("Saved (s):" + String(CanFillUpTime)); 
    //write2LCD(0,1, "Cal (s):" + String(CanFillUpTime));  
    write2LCD(0,0,"Multifiller " + String(mfVersion),0,1,"Cal (s):" + String(CanFillUpTime));
}

//GasValve1 - Co2 Co2 Purge Before filling
void GasValve1Co2PurgeBefore(){
  Serial.println("GasValve1Co2PurgeBefore");
   digitalWrite(GasValve1,HIGH);
   delay(Co2PurgeBeforeDelay);
   digitalWrite(GasValve1,LOW);
}

//GasValve2 - Co2 Co2 Purge Before filling
void GasValve2Co2PurgeBefore(){
  Serial.println("GasValve2Co2PurgeBefore");
   digitalWrite(GasValve2,HIGH);
   delay(Co2PurgeBeforeDelay);
   digitalWrite(GasValve2,LOW);
}

//GasValves - Co2 Co2 Purge Before filling
void GasValvesCo2PurgeBefore(){
  Serial.println("GasValvesCo2PurgeBefore");
    digitalWrite(GasValve1,HIGH);
    digitalWrite(GasValve2,HIGH);
    delay(Co2PurgeBeforeDelay);
    digitalWrite(GasValve1,LOW);
    digitalWrite(GasValve2,LOW);
}

//BeerValve1 - Fill can
void BeerValve1FillCan(){

    //Read from EEPROM
    String FetchedStrCanFillUpTimeMS = readEEPROM(0);
    int CanFillUpTime = FetchedStrCanFillUpTimeMS.toInt() * 1000;
    Serial.println("Read from EEPROM: " + String(CanFillUpTime));
    //int CanFillUpTime = EEPROM.read(0);
    Serial.println("Start - Beer Valve 1 Fill Can (CountDelayValueMs * " + String(CanFillUpTime) +")");
    write2LCD(0,0,"Filling up",0,1,"One Can (s):"+ String(FetchedStrCanFillUpTimeMS));

    digitalWrite(BeerValve1,HIGH);
    
    unsigned long TimeRightNow = millis();
    unsigned long currentFillupSeconds;
    int CanFillUpTimeSec = CanFillUpTime / 1000;
    boolean FillupComplete = false;
    
    while(FillupComplete == false){
      
      int currentFillupSeconds = (millis() - TimeRightNow)/1000;
      Serial.println(String(currentFillupSeconds)+ " " + String(CanFillUpTimeSec));
      write2LCD(0,0,"Fillup (s):",0,1,String(CanFillUpTimeSec)+"/"+String(currentFillupSeconds));
      delay(25);

      if(int(currentFillupSeconds) >= int(CanFillUpTimeSec)){
        Serial.println("Fillup complete!");
        FillupComplete = true;
      }
      
    }
    
    //delay(CanFillUpTime);
    digitalWrite(BeerValve1,LOW);

   TimeRightNow = 0;
   currentFillupSeconds = 0;
   FillupComplete = false;
   
   Serial.println("End - Beer Valve 1 Fill Can (s): " + String(CanFillUpTimeSec));
   write2LCD(0,0,"Done filling",0,1,"Time (s): " + String(CanFillUpTimeSec));
}

//BeerValve2 - Fill can
void BeerValve2FillCan(){
  Serial.println("BeerValve2FillCan");
    //Read from EEPROM
    String FetchedStrCanFillUpTimeMS = readEEPROM(0);
    int CanFillUpTime = FetchedStrCanFillUpTimeMS.toInt() * 1000;
    Serial.println("Read from EEPROM: " + String(CanFillUpTime));
    //int CanFillUpTime = EEPROM.read(0);
    Serial.println("Start - Beer Valve 1 Fill Can (CountDelayValueMs * " + String(CanFillUpTime) +")");
    digitalWrite(BeerValve2,HIGH);
   
   delay(CanFillUpTime);
   digitalWrite(BeerValve2,LOW);
   Serial.println("End - Beer Valve 1 Fill Can (ms): " + String(CanFillUpTime));

}

//BeerValve both - Fill cans
void BeerValveFillCans(){
    //Read from EEPROM
    String FetchedStrCanFillUpTimeMS = readEEPROM(0);
    int CanFillUpTime = FetchedStrCanFillUpTimeMS.toInt() * 1000;
    Serial.println("Read from EEPROM: " + String(CanFillUpTime));
    //int CanFillUpTime = EEPROM.read(0);
    Serial.println("Start - Beer Valve 1 Fill Can (CountDelayValueMs * " + String(CanFillUpTime) +")");
    //write2LCD(0,0,"Filling up",0,1,"Two Cans (s):"+ String(FetchedStrCanFillUpTimeMS));
    digitalWrite(BeerValve1,HIGH);
    digitalWrite(BeerValve2,HIGH);

    unsigned long TimeRightNow = millis();
    unsigned long currentFillupSeconds; 
    int CanFillUpTimeSec = (CanFillUpTime / 1000) * BothCanFillupComp; //Add compensation for both cans being filled
    boolean FillupComplete = false;
    
    while(FillupComplete == false){
      
      int currentFillupSeconds = (millis() - TimeRightNow)/1000;
      Serial.println(String(currentFillupSeconds)+ " " + String(CanFillUpTimeSec));
      write2LCD(0,0,"Fillup (s):",0,1,String(CanFillUpTimeSec)+"/"+String(currentFillupSeconds));
      delay(25);

      if(int(currentFillupSeconds) >= int(CanFillUpTimeSec)){
        Serial.println("Fillup complete!");
        FillupComplete = true;
      }
      
    }    
  
   //delay(CanFillUpTime);
   digitalWrite(BeerValve1,LOW);
   digitalWrite(BeerValve2,LOW);

   TimeRightNow = 0;
   currentFillupSeconds = 0;
   FillupComplete = false;
   
   Serial.println("End - Beer Valve 1/2 Fill Can (s): " + String(CanFillUpTimeSec));
   write2LCD(0,0,"Done filling",0,1,"Time: " + String(CanFillUpTimeSec));
   
}

//GasValve1 - Co2 Co2 Purge after filling
void GasValve1Co2PurgeAfter(){
  Serial.println("GasValve1Co2PurgeAfter");
  while(Co2PurgeAfterCount < Co2PurgeAfterCountLimit){
   Serial.print("+");
   digitalWrite(GasValve1,HIGH);
   delay(10);
   digitalWrite(GasValve1,LOW);
   delay(10);
   Co2PurgeAfterCount++;
  }
  Serial.println("+");
  Co2PurgeAfterCount = 0;
  //Safety
  digitalWrite(GasValve1,LOW);
}

//GasValve2 - Co2 Co2 Purge after filling
void GasValve2Co2PurgeAfter(){
  Serial.println("GasValve2Co2PurgeAfter");
  while(Co2PurgeAfterCount < Co2PurgeAfterCountLimit){
    Serial.print("+");
   digitalWrite(GasValve2,HIGH);
   delay(10);
   digitalWrite(GasValve2,LOW);
   delay(10);
   Co2PurgeAfterCount++;
  }
  Serial.println("+");
  Co2PurgeAfterCount = 0;
  //Safety
  digitalWrite(GasValve2,LOW);
}

//GasValves - Co2 Co2 Purge after filling
void GasValvesCo2PurgeAfter(){
  Serial.println("GasValvesCo2PurgeAfter");
  while(Co2PurgeAfterCount <= Co2PurgeAfterCountLimit){
    Serial.print("+");
    digitalWrite(GasValve1,HIGH);
   digitalWrite(GasValve2,HIGH);
   delay(25);
   digitalWrite(GasValve1,LOW);
   digitalWrite(GasValve2,LOW);
   delay(25);
   Co2PurgeAfterCount++;
   }
   Serial.println("+");
  Co2PurgeAfterCount = 0;
  //Safety
  digitalWrite(GasValve1,LOW);
  digitalWrite(GasValve2,LOW);
}

//Softstop - Just stop everything to be sure
void SoftStopFunction(){
  Serial.println("SoftStopFunction");
    digitalWrite(GasValve1,LOW);
    digitalWrite(GasValve2,LOW);
    digitalWrite(BeerValve1,LOW);
    digitalWrite(BeerValve2,LOW);
}

//Emergency Shutdown
void EmergencyShutDownButtonFunction(){
  Serial.println("EmergencyShutDownButtonFunction");
  while(digitalRead(EmergencyShutDownButton) == HIGH){
    Serial.print("+");
    digitalWrite(GasValve1,LOW);
    digitalWrite(GasValve2,LOW);
    digitalWrite(BeerValve1,LOW);
    digitalWrite(BeerValve2,LOW);
    delay(100);
  }
    digitalWrite(GasValve1,LOW);
    digitalWrite(GasValve2,LOW);
    digitalWrite(BeerValve1,LOW);
    digitalWrite(BeerValve2,LOW);
    Serial.println("Going into softstop");
    SoftStopFunction();
    
}


//Run first beerfiller
void BeerFiller1ButtonFunction(){
  Serial.println("BeerFiller 1 Button Function");
  write2LCD(0,0,"Co2 Purge",0,1,"first can");
  GasValve1Co2PurgeBefore();
  delay(25);
  write2LCD(0,0,"Start fillup",0,1,"...");
  BeerValve1FillCan();
  delay(25);
  GasValve1Co2PurgeAfter();
  delay(25);
  SoftStopFunction();
}

//Run both fillers
void BeerFiller12ButtonFunction(){
  Serial.println("BeerFiller 1-2 Button Function");
  write2LCD(0,0,"Co2 Purge",0,1,"both cans");
  GasValvesCo2PurgeBefore();
  delay(25);
  write2LCD(0,0,"Start fillup",0,1,"...");
  BeerValveFillCans();
  delay(25);
  GasValvesCo2PurgeAfter();
  delay(25);
  SoftStopFunction();
}

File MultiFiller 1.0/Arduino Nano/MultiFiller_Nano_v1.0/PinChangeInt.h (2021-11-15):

// This file is part of the PinChangeInt library for the Arduino.  This library will work on any ATmega328-based
// or ATmega2560-based Arduino, as well as the Sanguino or Mioduino.

// Most of the pins of an Arduino Uno use Pin Change Interrupts, and because of the way the ATmega interrupt
// system is designed it is difficult to trigger an Interrupt Service Request off of any single pin, and on
// any change of state (either rising, or falling, or both).  The goal of this library is to make it easy for
// the programmer to attach an ISR so it will trigger on any change of state on any Pin Change Interrupt pin.

// (NOTE TO SELF: Update the PCINT_VERSION define, below) -----------------
#define PCINT_VERSION 2402
/*
Copyright 2008 Chris J. Kiick
Copyright 2009-2011 Lex Talionis
Copyright 2010-2014 Michael Schwager (aka, "GreyGnome")

    Licensed under the Apache License, Version 2.0 (the "License");
    you may not use this file except in compliance with the License.
    You may obtain a copy of the License at

    http://www.apache.org/licenses/LICENSE-2.0

    Unless required by applicable law or agreed to in writing, software
    distributed under the License is distributed on an "AS IS" BASIS,
    WITHOUT WARRANTIES OR CONDITIONS OF ANY KIND, either express or implied.
    See the License for the specific language governing permissions and
    limitations under the License.
*/

/*
 * QUICKSTART
 *
 * For the beginners/lazy/busy/wreckless:
 * To attach an interrupt to your Arduino Pin, calling your function "userFunc", and acting on
 * the "mode", which is a change in the pin's state; either RISING or FALLING or CHANGE:
 *		attachPinChangeInterrupt(pin,userFunc,mode)
 * Your function must not return any values and it cannot take any arguments (that is, its definition
 * has to look like this:
 *		void userFunc() {
 *		  ...your code here...
 *		}
 *
 * That's it. Everything else are details.
 *
 * If you need to exchange information to/from the interrupt, you can use global volatile variables.
 * See the example for more information.
 *
 *	You probably will not need to do this, but later in your sketch you can detach the interrupt:
 *		detachPinChangeInterrupt(pin)
 *
 *	If you want to see what the *last* pin that triggered an interrupt was, you can get it this way:
 *		getInterruptedPin()
 *	Note: If you have multiple pins that are triggering interrupts and they are sufficiently fast,
 *	you will not be able to find all the pins that interrupted.
*/

//
// For the beginners
//
#define	detachPinChangeInterrupt(pin)				PCintPort::detachInterrupt(pin)
#define	attachPinChangeInterrupt(pin,userFunc,mode)	PCintPort::attachInterrupt(pin, &userFunc,mode)
#define getInterruptedPin()							PCintPort::getArduinoPin()

// We use 4-character tabstops, so IN VIM:  <esc>:set ts=4 sw=4 sts=4
// ...that's: ESCAPE key, colon key, then
//		"s-e-t SPACE key t-s = 4 SPACE key s-w = 4 SPACE key s-t-s = 4"

/*
 * 	This is the PinChangeInt library for the Arduino.
	This library provides an extension to the interrupt support for arduino by adding pin change
	interrupts, giving a way for users to have interrupts drive off of any pin (ATmega328-based
	Arduinos) and by the Port B, J, and K pins on the Arduino Mega and its ilk (see the README file).

	See the README for license, acknowledgments, and other details (especially concerning the Arduino MEGA).

	See google code project for latest, bugs and info http://code.google.com/p/arduino-pinchangeint/
	See github for the bleeding edge code: https://github.com/GreyGnome/PinChangeInt
	For more information Refer to avr-gcc header files, arduino source and atmega datasheet.

	This library was inspired by and derived from Chris J. Kiick's PCInt Arduino Playground
	example here: http://www.arduino.cc/playground/Main/PcInt
	Nice job, Chris!
*/
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

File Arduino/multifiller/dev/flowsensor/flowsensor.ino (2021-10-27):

/*
YF‐ S201 Water Flow Sensor
Water Flow Sensor output processed to read in litres/hour
Adaptation Courtesy: www.hobbytronics.co.uk
*/
volatile int flow_frequency; // Measures flow sensor pulses
unsigned int l_hour; // Calculated litres/hour
unsigned char flowsensor = 2; // Sensor Input
unsigned long currentTime;
unsigned long cloopTime;
unsigned long read_pulses;
int Lpulses = 10000; // the amount of pulses for 1 liter of liquid
unsigned long liquid_ml; // liquid_ml = 1000/(1L_pulses / read_pulses); // ml / ((1L * pulses) / inputSignal )



void flow () // Interrupt function
{
   flow_frequency++;
   Serial.println(flow_frequency);
}
void setup()
{
   pinMode(flowsensor, INPUT);
   digitalWrite(flowsensor, HIGH); // Optional Internal Pull-Up
   Serial.begin(9600);
   //attachInterrupt(0, flow, RISING); // Setup Interrupt
   //sei(); // Enable interrupts
   currentTime = millis();
   cloopTime = currentTime;
}
void loop ()
{
int aa = 0;
boolean flowing = true;

    while(flowing == true){

      delay(25);
      //read flowsensor
      read_pulses += digitalRead(flowsensor);
      Serial.println("Read pulses: " + String(read_pulses));

      aa++;
      if(aa < 200){
        flowing = false;
          liquid_ml = 1000/(Lpulses / read_pulses);
          Serial.println("Read liquid:" + String(liquid_ml));
      }
    }


    //Serial.println("Read pulses: " + String(read_pulses));
    //Flowsensor
    liquid_ml = 1000/(Lpulses / read_pulses);
    Serial.println("Read liquid:" + String(liquid_ml));

}

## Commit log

2021-10-10 Update multifiller.ino
    Save full delaytime/calibration time in milliseconds in eeprom
2021-10-11 Update multifiller.ino
    Added Emergency stop with pin interrupt on A10.
2021-10-12 Updated short and longpress calibration
    [multifiller.ino]
2021-10-17 3d prints
    [Valve-clamp.stl, line-guide.stl]
2021-11-17 new stuff
    [CAN_Shelf.stl]

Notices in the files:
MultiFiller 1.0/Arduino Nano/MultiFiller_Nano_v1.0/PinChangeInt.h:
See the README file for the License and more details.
